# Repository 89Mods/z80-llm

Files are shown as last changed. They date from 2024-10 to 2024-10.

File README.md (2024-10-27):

# What?

Z80-LLM is a bunch of code meant to enable a Z80 CPU to run a GPT-2-Medium sized LLM, but larger should theoretically be possible. This will hopefully finally bring modern AI into the retro-computing era. The code is written in simple C and should be easily portable to platforms not just based on the Z80, but also other retro CPUs with a C compiler toolchain.

# Why?

# How?

## Hardware

The demo hardware consist only of a Z80, 32KiB of ROM and some SRAM. 32KiB is not enough, so the final 16KiB of the address range is paged 16-ways to get a bit more. Though technically less memory usage is possible at the cost of speed. Obviously, running a LLM requires still more memory, so two PIO chips drive a PATA interface to a disk drive, where data is paged in and out of raw disk blocks to get even more space for matrices and vectors. Part of the disk is formated, though, to hold the network parameters.

Two UARTs are provided: one for standard output and a second to print a verbose log.

The schematics and PCB layout files can be found in the folder `Hardware`.

## LLM

The code to pre-train the LLM was written using libtorch in C++, using custom code for implementation of the attention layers, to make translating it into standalone C easier. This code was then supplied with a dataset of book texts and trained on a cloud compute instance containing a RTX4090 that was fed a large budget of 27.16$. The resulting LLM is good enough at generating basic, coherent text for the purposes of demonstration.

This code can be found in the folder `libtorch_llm`.

## Standalone C program

I started out by writing a standalone, single file C program on my desktop PC that can run the LLM, to have a working reference point when writing the code for the Z80.
Still, this program already contains key aspects of what is required on the Z80, such as parsing parameters from files and emulating matrices being stored in a block device.
The resulting code only depends on the standard library and compiles into a tiny executable on Linux.

This code can be found in the folder `c_pgm`.

## Z80 Firmware

z88dk was used to create the program to run the LLM on a Z80. It works as described above by using space on a connected disk drive as memory for matrices and the paged SRAM as cache for that memory. To load the parameters, a filesystem partition is also present on the disk. My choice of filesystem is, of course, ext4, to further modernize the software design. Only basic filesystem read access is supported, but code to handle checksum checking and symlink parsing is present and can be enabled, if required. This allows easy copying and modification of the network parameters on the disk from any common Linux distro!

Standard IEEE 32-bit floats are used for computation. I did experiment with 16-bit floats and fixed-point numbers, but they produced completely broken results due to precission errors. So floats are used, for maximum compatibility! Though, one optimization I did make use of is LUTs. Notably, the GeLU nonlinearity is implemented through a LUT in a file, which I found to be faster.

A byte-pair-encoder almost identical to the one used in GPT-2 is used for tokenization. I will admit, the code I wrote for it is not the best, but it successfully runs on the Z80, so I am happy with it. It also uses data stored on the filesystem to do the encoding.

Note: the resulting code does not fit into the 32KiB ROM. To work around this, the CPU copies some blocks from the disk to SRAM at bootup, allowing code to overflow into RAM. Any code changes require not only re-programming of the ROM, but also an update of the disk image. I apologize for this inconvenience.

This code can be found in the folder `Z80`.

# Speed

At 8MHz and using a SSD as the disk drive for maximum throughput, I have approximated, using simulation, a time of 1,292,518 minutes per token, or roughly 2.4 years. Upgrading to a 20MHz Z80 should cut that down to 1 year, and I am investigating speeds using a AM9511 to accelerate the floating-point computations.

# Usage

The intended method for getting this beast running is to put together a disk image on your PC, and then dd-ing it to a real drive. Open a terminal at the root of this repository.

First, create a blank file that is less than or equal in capacity to your target physical drive. I am using a SSD with slightly less than 16GiB capacity, so I will use a 3G large image: `dd if=/dev/zero of=./disk.img bs=1M count=3072`

Next, it needs a filesystem partition. It can’t span the whole disk, as the program requires a bit of free space after the filesystem partition, which it will use as memory. Use fdisk for this: `fdisk ./disk.img`

Create a MBR partition table (`o`) and add a new partition (`n`), which is to be primary (`p`) and number 1 (`1`). First sector has to be 2048, as the first blocks of the disk past the MBR will store Z80 bytecode that is overflowing from ROM into RAM. For the size of the partition, I go with 2G (`+2G`) so mkfs doesn’t make a fuzz on the next step.

`w` will tell fdisk to write changes to the disk image and exit. To continue, the disk image needs to be set up as a loop device, so it can be worked on directly: `sudo losetup -fP disk.img`. For the next steps, make sure you are targeting the correct device, or you may corrupt a part of your OS! `lsblk` shows one new device, `loop0`, after the previous command, so that has to be it.

Simply doing `sudo mkfs.ext4 /dev/loop0p1` will create the ext4 file system on the partition that was just created. Note: it is possible your distro’s mkfs config enables filesystem features not supported by my code. If this happens, you can comment out the FS feature check in `Z80/ext4.c`. In most cases, it will still work.

At this point, you should be able to minimize the terminal window and continue in your DE’s file browser, as the freshly formatted partition should show up there, like a removable drive. Open it. You can change the permissions to make these next steps easier if you want, it won’t affect things on the Z80.

For now, I will only describe how to install the weights from my pre-trained model. Download the files [here](https://files.tholin.dev/Public/model.tar.gz) and extract into the root of the partition.

Next is the data files for the tokenizer. Navigate to `libtorch_llm/data/` directory and simply run the `prepare_vocab.sh` bash script. I decided to use GPT-2’s actual tokenizer configs, and this script will download them and apply any required modifications. You can then copy the entire `data` folder to the root of the ext4 partition.

Note: you will need nodejs installed to run one of the helper scripts. Yes, I am aware of how absolutely insane the language spread of this repository is.

Once done, the root of the partition should have three entries `LUTs`, `model` and `data`. You can now un-mount the partition. To remove the loop device, I like to use this handy command, which destroys all loop devices associated with a specific file: `losetup -j ./disk.img | grep -o "/dev/loop[0-9][0-9]*" | xargs -L1 sudo losetup -d`.

Now, finally, comes the step of building the Z80 code. Start by installing [z88dk](https://github.com/z88dk/z88dk/) in whichever way you prefer. Then, navigate a terminal to the `Z80` directory in this repo and simply do `make`. The makefile should do everything for you, including modifying the disk image with the overflowing binary (assuming you created it in the right place).

Lastly, get out whatever ROM programmer you use and burn `EPROM.bin` onto a memory chip of your choice. In parallel, start copying the disk image to a real drive, preferably through dd.

Congratulations! You are now ready to wait 2.5 years for your Z80 to say a single word to you!

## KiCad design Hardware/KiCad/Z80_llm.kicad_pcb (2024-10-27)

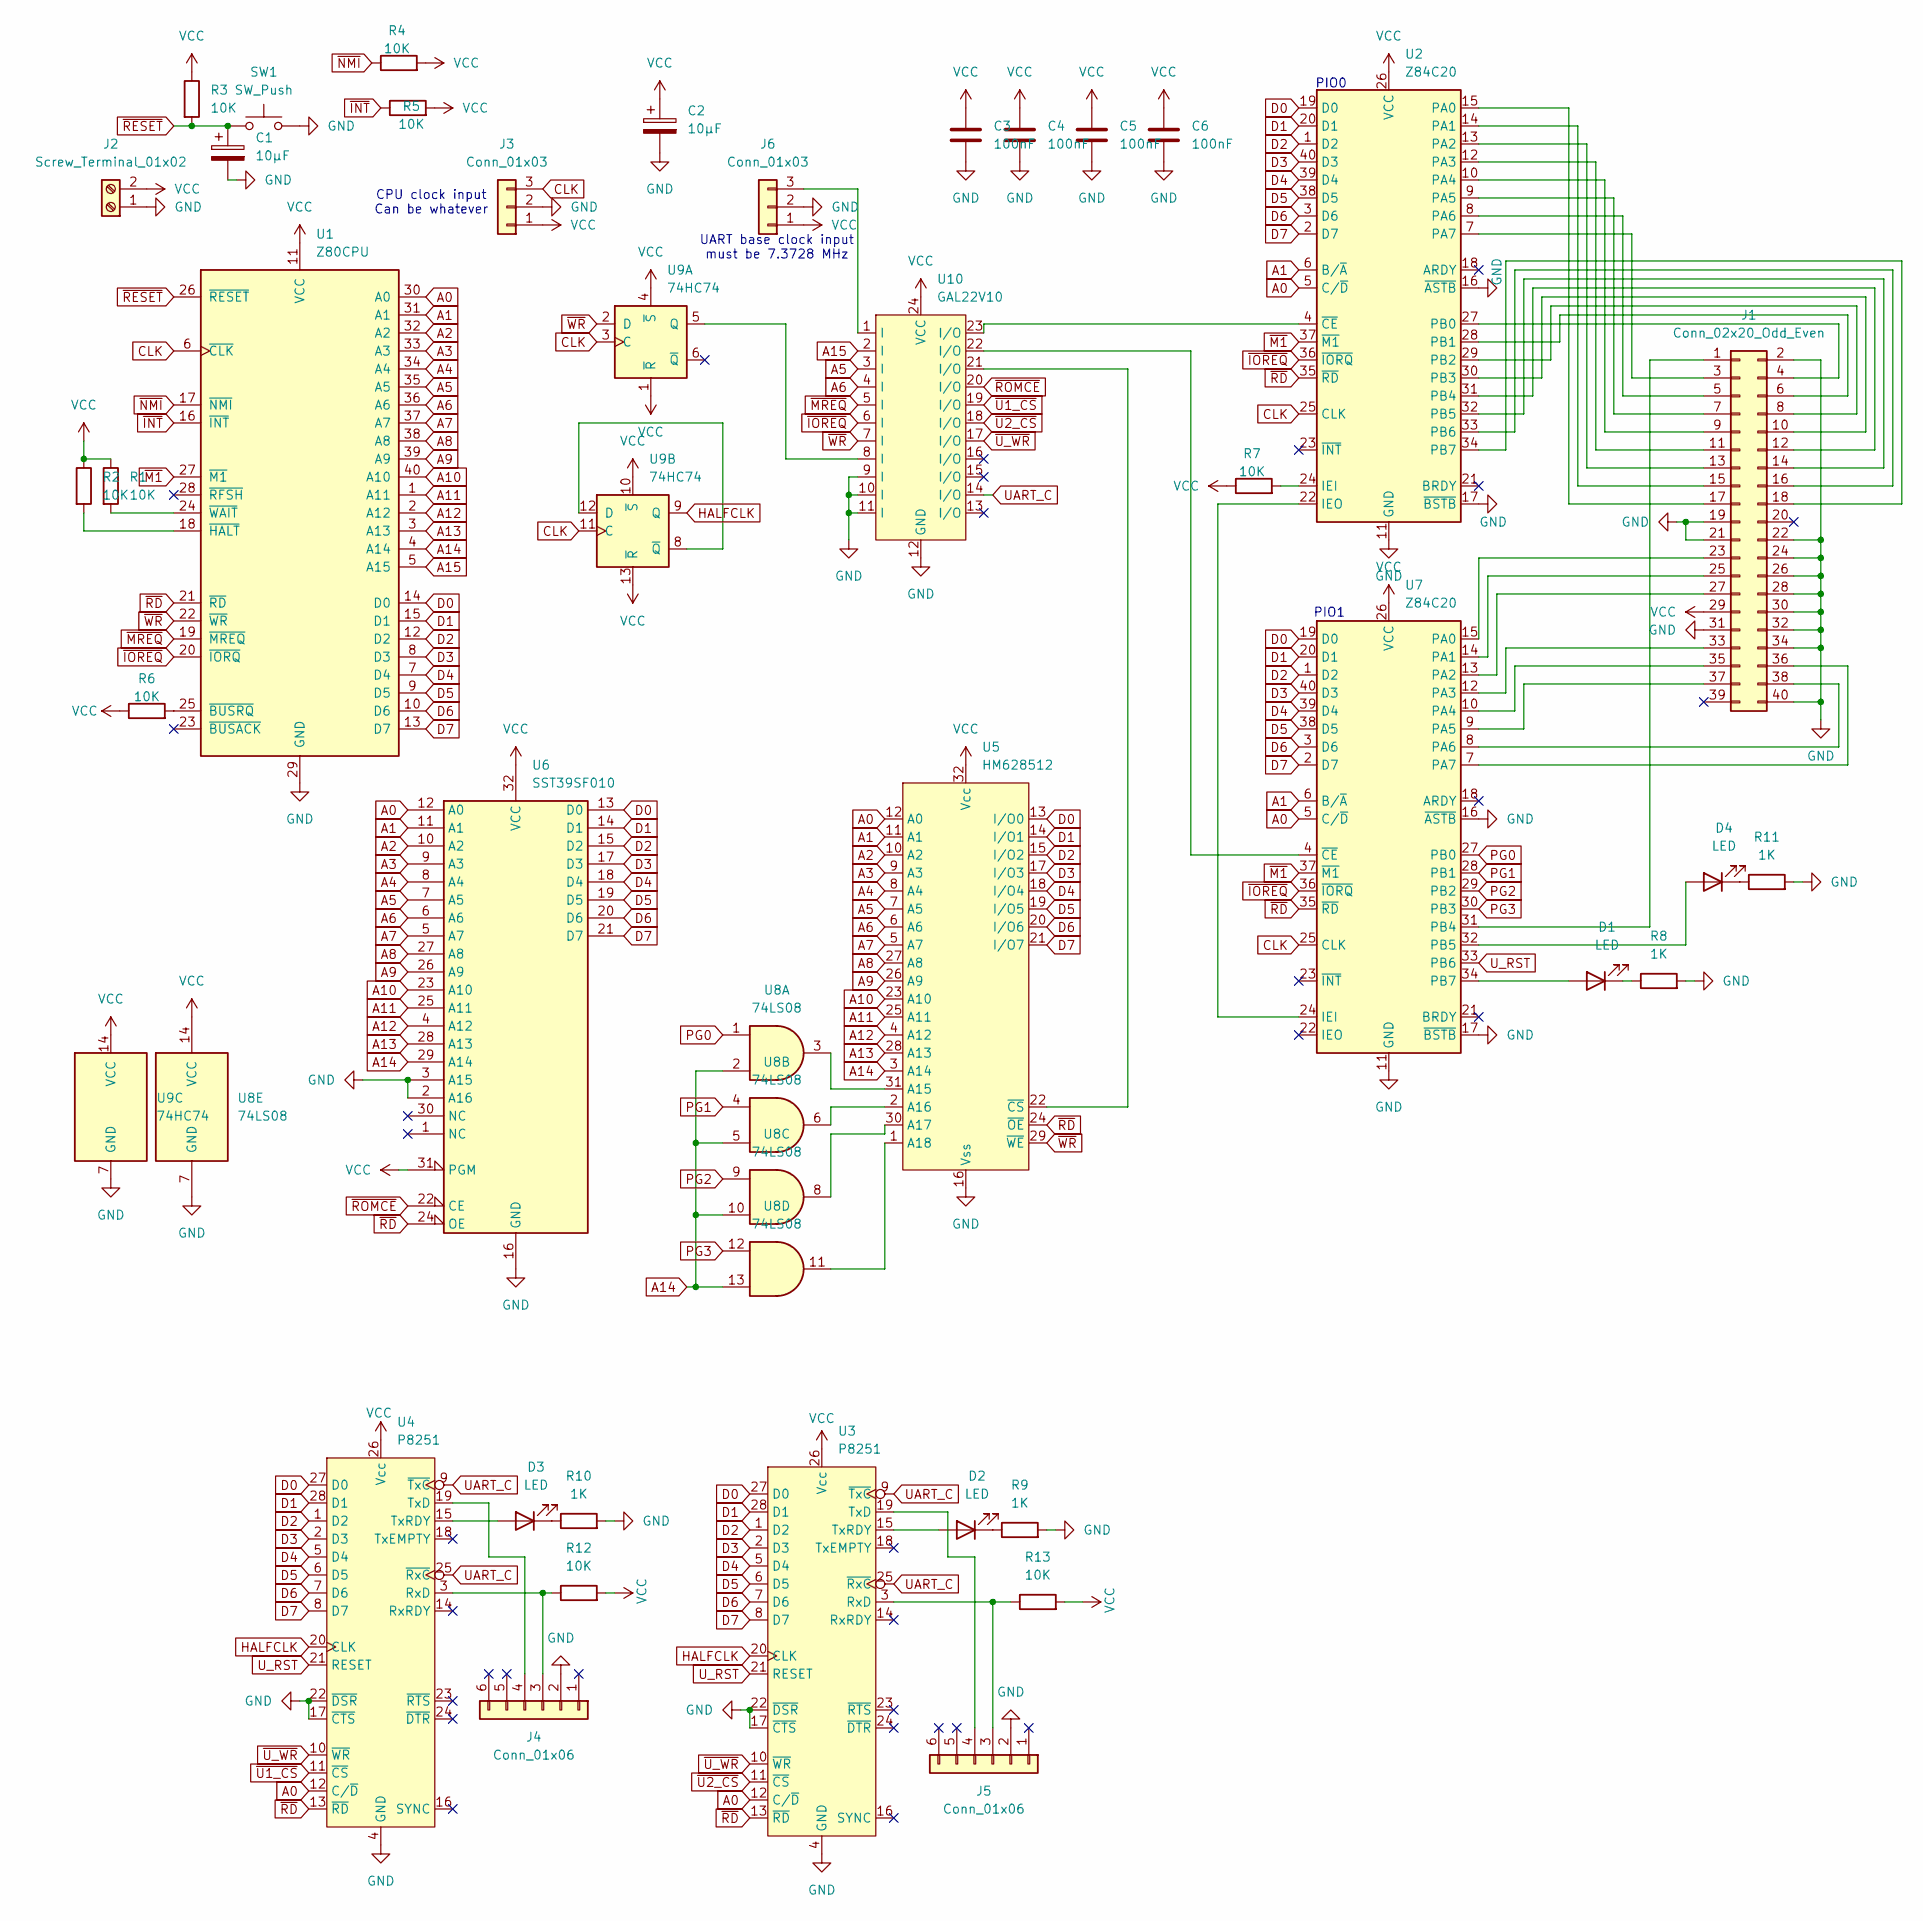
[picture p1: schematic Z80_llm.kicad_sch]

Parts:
C1, C2: 10µF; CP_Radial_D4.0mm_P2.00mm
C3, C4, C5, C6: 100nF; C_0805_2012Metric_Pad1.18x1.45mm_HandSolder
D1: LED; LED_D5.0mm
D2, D3, D4: LED; LED_D3.0mm
J1: Conn_02x20_Odd_Even; PinHeader_2x20_P2.54mm_Vertical
J2: Screw_Terminal_01x02; TerminalBlock_bornier-2_P5.08mm
J3, J6: Conn_01x03; PinHeader_1x03_P2.54mm_Vertical
J4, J5: Conn_01x06; PinHeader_1x06_P2.54mm_Vertical
R1, R2, R3, R4, R5, R6, R7, R12, R13: 10K; R_1206_3216Metric_Pad1.30x1.75mm_HandSolder
R8, R9, R10, R11: 1K; R_1206_3216Metric_Pad1.30x1.75mm_HandSolder
SW1: SW_Push; SW_PUSH_6mm
U1: Z80CPU; DIP-40_W15.24mm
U2, U7: Z84C20; DIP-40_W15.24mm
U3, U4: P8251; DIP-28_W15.24mm
U5: HM628512; DIP-32_W15.24mm
U6: SST39SF010; DIP-32_W15.24mm
U8: 74LS08; SO-14_3.9x8.65mm_P1.27mm
U9: 74HC74; DIP-14_W7.62mm
U10: GAL22V10; DIP-24_W7.62mm_Socket

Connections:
A0: U1.30 (A0), U2.5 (C/~D), U3.12 (C/~D), U4.12 (C/~D), U5.12 (A0), U6.12 (A0), U7.5 (C/~D)
A1: U1.31 (A1), U2.6 (B/~A), U5.11 (A1), U6.11 (A1), U7.6 (B/~A)
A2: U1.32 (A2), U5.10 (A2), U6.10 (A2)
A3: U1.33 (A3), U5.9 (A3), U6.9 (A3)
A4: U1.34 (A4), U5.8 (A4), U6.8 (A4)
A5: U1.35 (A5), U5.7 (A5), U6.7 (A5), U10.3 (I)
A6: U1.36 (A6), U5.6 (A6), U6.6 (A6), U10.4 (I)
A7: U1.37 (A7), U5.5 (A7), U6.5 (A7)
A8: U1.38 (A8), U5.27 (A8), U6.27 (A8)
A9: U1.39 (A9), U5.26 (A9), U6.26 (A9)
A10: U1.40 (A10), U5.23 (A10), U6.23 (A10)
A11: U1.1 (A11), U5.25 (A11), U6.25 (A11)
A12: U1.2 (A12), U5.4 (A12), U6.4 (A12)
A13: U1.3 (A13), U5.28 (A13), U6.28 (A13)
A14: U1.4 (A14), U5.3 (A14), U6.29 (A14), U8.2, U8.5, U8.10, U8.13
A15: U1.5 (A15), U10.2 (I)
CLK: J3.3, U1.6 (~CLK), U2.25 (CLK), U7.25 (CLK), U9.3 (C), U9.11 (C)
D0: U1.14 (D0), U2.19 (D0), U3.27 (D0), U4.27 (D0), U5.13 (I/O0), U6.13 (D0), U7.19 (D0)
D1: U1.15 (D1), U2.20 (D1), U3.28 (D1), U4.28 (D1), U5.14 (I/O1), U6.14 (D1), U7.20 (D1)
D2: U1.12 (D2), U2.1 (D2), U3.1 (D2), U4.1 (D2), U5.15 (I/O2), U6.15 (D2), U7.1 (D2)
D3: U1.8 (D3), U2.40 (D3), U3.2 (D3), U4.2 (D3), U5.17 (I/O3), U6.17 (D3), U7.40 (D3)
D4: U1.7 (D4), U2.39 (D4), U3.5 (D4), U4.5 (D4), U5.18 (I/O4), U6.18 (D4), U7.39 (D4)
D5: U1.9 (D5), U2.38 (D5), U3.6 (D5), U4.6 (D5), U5.19 (I/O5), U6.19 (D5), U7.38 (D5)
D6: U1.10 (D6), U2.3 (D6), U3.7 (D6), U4.7 (D6), U5.20 (I/O6), U6.20 (D6), U7.3 (D6)
D7: U1.13 (D7), U2.2 (D7), U3.8 (D7), U4.8 (D7), U5.21 (I/O7), U6.21 (D7), U7.2 (D7)
GND: C1.2, C2.2, C3.2, C4.2, C5.2, C6.2, J1.2, J1.19, J1.21, J1.22, J1.24, J1.26, J1.28, J1.30, J1.31, J1.32, J1.34, J1.40, J2.1, J3.2, J4.2, J5.2, J6.2, R8.2, R9.2, R10.2, R11.2, SW1.2, U1.29 (GND), U2.11 (GND), U2.16 (~ASTB), U2.17 (~BSTB), U3.4 (GND), U3.17 (~CTS), U3.22 (~DSR), U4.4 (GND), U4.17 (~CTS), U4.22 (~DSR), U5.16 (Vss), U6.2 (A16), U6.3 (A15), U6.16 (GND), U7.11 (GND), U7.16 (~ASTB), U7.17 (~BSTB), U8.7 (GND), U9.7 (GND), U10.9 (I), U10.10 (I), U10.11 (I), U10.12 (GND)
HALFCLK: U3.20 (CLK), U4.20 (CLK), U9.9 (Q)
unnamed: D1.2 (A), U7.34 (PB7)
unnamed: D1.1 (K), R8.1
unnamed: D2.2 (A), U3.15 (TxRDY)
unnamed: D2.1 (K), R9.1
unnamed: D3.2 (A), U4.15 (TxRDY)
unnamed: D3.1 (K), R10.1
unnamed: D4.2 (A), U7.32 (PB5)
unnamed: D4.1 (K), R11.1
unnamed: J1.1, U7.31 (PB4)
unnamed: J1.3, U2.7 (PA7)
unnamed: J1.4, U2.27 (PB0)
unnamed: J1.5, U2.8 (PA6)
unnamed: J1.6, U2.28 (PB1)
unnamed: J1.7, U2.9 (PA5)
unnamed: J1.8, U2.29 (PB2)
unnamed: J1.9, U2.10 (PA4)
unnamed: J1.10, U2.30 (PB3)
unnamed: J1.11, U2.12 (PA3)
unnamed: J1.12, U2.31 (PB4)
unnamed: J1.13, U2.13 (PA2)
unnamed: J1.14, U2.32 (PB5)
unnamed: J1.15, U2.14 (PA1)
unnamed: J1.16, U2.33 (PB6)
unnamed: J1.17, U2.15 (PA0)
unnamed: J1.18, U2.34 (PB7)
unnamed: J1.23, U7.15 (PA0)
unnamed: J1.25, U7.14 (PA1)
unnamed: J1.27, U7.13 (PA2)
unnamed: J1.33, U7.12 (PA3)
unnamed: J1.35, U7.10 (PA4)
unnamed: J1.36, U7.7 (PA7)
unnamed: J1.37, U7.9 (PA5)
unnamed: J1.38, U7.8 (PA6)
unnamed: J4.3, R12.1, U4.3 (RxD)
unnamed: J4.4, U4.19 (TxD)
unnamed: J5.3, R13.1, U3.3 (RxD)
unnamed: J5.4, U3.19 (TxD)
unnamed: J6.3, U10.1 (I)
unnamed: R6.2, U1.25 (~BUSRQ)
unnamed: R2.2, U1.18 (~HALT)
unnamed: R1.2, U1.24 (~WAIT)
unnamed: R7.2, U2.24 (IEI)
unnamed: U2.22 (IEO), U7.24 (IEI)
unnamed: U2.4 (~CE), U10.23 (I/O)
unnamed: U5.31 (A15), U8.3
unnamed: U5.2 (A16), U8.6
unnamed: U5.30 (A17), U8.8
unnamed: U5.1 (A18), U8.11
unnamed: U5.22 (~CS), U10.21 (I/O)
unnamed: U7.4 (~CE), U10.22 (I/O)
unnamed: U9.5 (Q), U10.8 (I)
unnamed: U9.8 (~Q), U9.12 (D)
PG0: U7.27 (PB0), U8.1
PG1: U7.28 (PB1), U8.4
PG2: U7.29 (PB2), U8.9
PG3: U7.30 (PB3), U8.12
UART_C: U3.9 (~TxC), U3.25 (~RxC), U4.9 (~TxC), U4.25 (~RxC), U10.14 (I/O)
U_RST: U3.21 (RESET), U4.21 (RESET), U7.33 (PB6)
VCC: C2.1, C3.1, C4.1, C5.1, C6.1, J1.29, J2.2, J3.1, J6.1, R1.1, R2.1, R3.1, R4.2, R5.2, R6.1, R7.1, R12.2, R13.2, U1.11 (VCC), U2.26 (VCC), U3.26 (Vcc), U4.26 (Vcc), U5.32 (Vcc), U6.31 (PGM), U6.32 (VCC), U7.26 (VCC), U8.14 (VCC), U9.1 (~R), U9.4 (~S), U9.10 (~S), U9.13 (~R), U9.14 (VCC), U10.24 (VCC)
~INT: R5.1, U1.16 (~INT)
~IOREQ: U1.20 (~IORQ), U2.36 (~IORQ), U7.36 (~IORQ), U10.6 (I)
~M1: U1.27 (~M1), U2.37 (~M1), U7.37 (~M1)
~MREQ: U1.19 (~MREQ), U10.5 (I)
~NMI: R4.1, U1.17 (~NMI)
~RD: U1.21 (~RD), U2.35 (~RD), U3.13 (~RD), U4.13 (~RD), U5.24 (~OE), U6.24 (OE), U7.35 (~RD)
~RESET: C1.1, R3.2, SW1.1, U1.26 (~RESET)
~ROMCE: U6.22 (CE), U10.20 (I/O)
~U1_CS: U4.11 (~CS), U10.19 (I/O)
~U2_CS: U3.11 (~CS), U10.18 (I/O)
~U_WR: U3.10 (~WR), U4.10 (~WR), U10.17 (I/O)
~WR: U1.22 (~WR), U5.29 (~WE), U9.2 (D), U10.7 (I)

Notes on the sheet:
UART base clock input must be 7.3728 MHz
CPU clock input Can be whatever
PIO0
PIO1

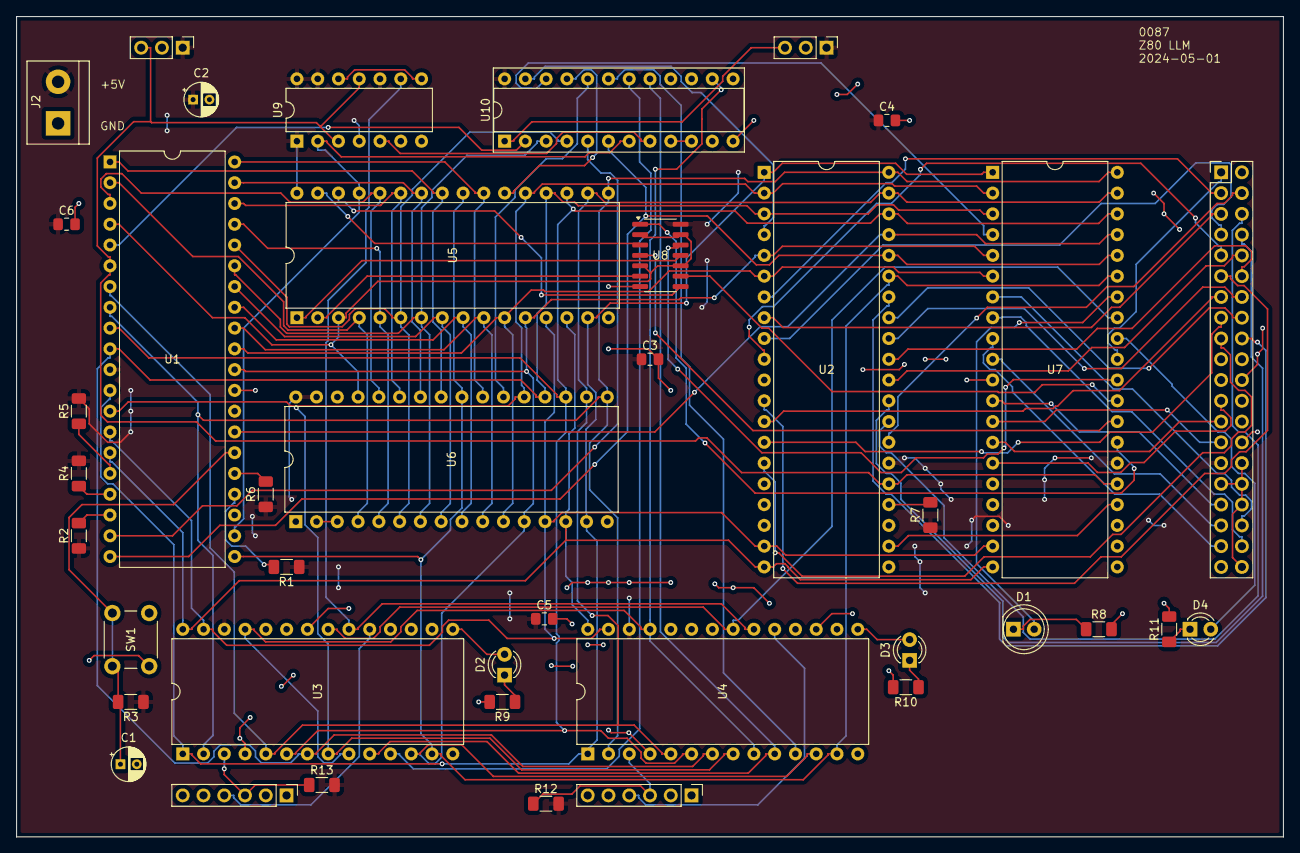
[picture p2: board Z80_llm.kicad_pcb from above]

Board: 2 copper layers, 154.9 x 100.3 mm, 40 parts (0 on the bottom side), 98 nets.

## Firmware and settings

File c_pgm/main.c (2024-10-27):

#include <stdio.h>
#include <stdint.h>
#include <stdlib.h>
#include <math.h>

#include "crc16.h"
#include "tokenizer.h"

#define EMULATED_BUFFERS

void print_cv_sample();

float f_inv_sqrt(float x) {
	if(x < 0) x = -x;
	float x2,y = 0;
	uint32_t i;

	if(x == 0.0f) return 0.0f;
	x2 = x * 0.5f;
	i = *(uint32_t *)&x;
	i = 0x5f3759df - (i >> 1);
	y = *(float *)&i;
	y *= 1.5f - (x2 * y * y);
	y *= 1.5f - (x2 * y * y);
	y *= 1.5f - (x2 * y * y);
	return y;
}

/*
 * Emulate Z80 disk buffers
 */
float context_vec[512][1024];
void cv_write_arr(uint16_t x, float* vals, uint16_t len) {
    for(uint16_t i = 0; i < len; i++) context_vec[x][i] = vals[i];
}

void cv_write_arr64(uint16_t x, uint16_t y, float* vals) {
	for(uint16_t i = 0; i < 64; i++) context_vec[x][i + y*64] = vals[i];
}

void cv_read_arr(uint16_t x, float* vals, uint16_t len) {
    for(uint16_t i = 0; i < len; i++) vals[i] = context_vec[x][i];
}

float context_shortcut[512][1024];
void cv_create_shortcut() {
	float raw[1024];
	for(uint16_t i = 0; i < 512; i++) {
		cv_read_arr(i, raw, 1024);
		for(uint16_t j = 0; j < 1024; j++) context_shortcut[i][j] = raw[j];
	}
}

void cv_add_shortcut() {
	float buff[1024];
	float buff2[1024];
	for(uint16_t i = 0; i < 512; i++) {
		cv_read_arr(i, buff, 1024);
		for(uint16_t j = 0; j < 1024; j++) buff2[j] = context_shortcut[i][j];
		for(uint16_t j = 0; j < 1024; j++) buff[j] += buff2[j];
		cv_write_arr(i, buff, 1024);
	}
}

float context_copy[512][1024]; //For when an operation needs to both update the context vector while needing its old values again
void cv_create_copy() {
	float raw[1024];
	for(uint16_t i = 0; i < 512; i++) {
		cv_read_arr(i, raw, 1024);
		for(uint16_t j = 0; j < 1024; j++) context_copy[i][j] = raw[j];
	}
}

void cv_read_copy_arr(uint16_t x, float* vals, uint16_t len) {
    for(uint16_t i = 0; i < len; i++) vals[i] = context_copy[x][i];
}

FILE* gelu_lut;

float f_gelu(float xf) {
	int32_t xi = (int32_t)(xf * 65536.0f);
	if(xi >= 0x00100000) return xf;
	if(xi <= -0x00100000) return 0.0f;
	uint32_t faddr = xi * 4;
	if(xi < 0) {
		xi = -xi;
		faddr = xi * 4 + 0x00100000*4;
	}
	fseek(gelu_lut, faddr, SEEK_SET);
	int32_t res;
	fread(&res, 1, 4, gelu_lut);
	return (float)res / 65536.0f;
}

typedef struct {
	uint16_t rows;
	uint16_t cols;
	uint32_t start_block;
#ifdef EMULATED_BUFFERS
	float* data;
#endif
} matrix_buff;

void mb_read_row(matrix_buff* bf, uint16_t row, float* vals) {
	for(uint16_t i = 0; i < bf->cols; i++) vals[i] = bf->data[(uint32_t)row * (uint32_t)bf->cols + i];
}

void mb_write_row(matrix_buff* bf, uint16_t row, float* vals) {
	for(uint16_t i = 0; i < bf->cols; i++) bf->data[(uint32_t)row * (uint32_t)bf->cols + i] = vals[i];
}

void mb_write_block(matrix_buff* bf, uint16_t row, uint16_t row_block, float* vals) {
	for(uint16_t i = 0; i < 512/4; i++) bf->data[(uint32_t)row * (uint32_t)bf->cols + i + row_block * (512/4)] = vals[i];
}

matrix_buff keys_matrix;
matrix_buff queries_matrix;
matrix_buff values_matrix;
matrix_buff values_transposed_matrix;
matrix_buff kq_matrix;
matrix_buff ff_matrix;

uint32_t cv_hash() {
    uint32_t hash = 0;
    float raw[1024];
    for(int i = 0; i < 512; i++) {
        cv_read_arr(i, raw, 1024);
        uint32_t crc = (uint32_t)gen_crc16((uint8_t*)raw, 1024*4);
        if(i % 2) {
            hash ^= crc << 16;
        }else {
            hash ^= crc;
        }
    }
    return hash;
}

void batch_norm(FILE* bparams) {
	float buff[1024];
	float buff2[1024];
	float* mean = buff2;
	float* var = buff2 + 512;
	for(uint16_t i = 0; i < 512; i++) {
		cv_read_arr(i, buff, 1024);
		mean[i] = 0;
		for(int j = 0; j < 1024; j++) mean[i] += buff[j];
		mean[i] = mean[i] / 1024.0f;
	}
	for(uint16_t i = 0; i < 512; i++) {
		cv_read_arr(i, buff, 1024);
		var[i] = 0;
		for(int j = 0; j < 1024; j++) {
			buff[j] -= mean[i];
			var[i] += buff[j] * buff[j];
		}
		var[i] = var[i] / 1023.0f;
		var[i] = f_inv_sqrt(var[i]);
		//if(i < 20) printf("%f %f\r\n", sqrt(f_tofloat(var[i])), f_tofloat(f_sqrt(var[i])));
	}
	
	for(uint16_t i = 0; i < 512; i++) {
		cv_read_arr(i, buff, 1024);
		for(int j = 0; j < 1024; j++) {
			buff[j] -= mean[i];
			buff[j] = buff[j] * var[i];
		}
		cv_write_arr(i, buff, 1024);
	}
	
	rewind(bparams);
	fread(buff2, 1024, 4, bparams);
	
	for(uint16_t i = 0; i < 512; i++) {
		cv_read_arr(i, buff, 1024);
		for(int j = 0; j < 1024; j++) buff[j] = buff[j] * buff2[j];
		cv_write_arr(i, buff, 1024);
	}
	
	fread(buff2, 1024, 4, bparams);
	for(uint16_t i = 0; i < 512; i++) {
		cv_read_arr(i, buff, 1024);
		for(int j = 0; j < 1024; j++) buff[j] += buff2[j];
		cv_write_arr(i, buff, 1024);
		//if(i == 0) for(int j = 0; j < 20; j++) printf("%f\r\n", f_tofloat(buff[j]));
	}
}

void matrix_multiply_with_embeddings(FILE* weights_file, matrix_buff* output) {
	float buffer[1024];
	float buffer2[1024];
	float buffer3[2048];
	for(uint16_t i = 0; i < output->rows; i++) {
		cv_read_copy_arr(i, buffer, 1024);
		rewind(weights_file);
		for(uint16_t j = 0; j < output->cols; j++) {
			fread(buffer2, 4, 1024, weights_file);
			float sum = 0;
			for(uint16_t k = 0; k < 1024; k++) sum += buffer[k] * buffer2[k];
			buffer3[j] = sum;
		}
		mb_write_row(output, i, buffer3);
	}
}

void feed_forward(FILE* in_params, FILE* out_params) {
	cv_create_copy();
	matrix_multiply_with_embeddings(in_params, &ff_matrix);
	float buffer[2048];
	float buffer2[2][2048];
	//Add bias
	fseek(in_params, 1024*2048*sizeof(float), SEEK_SET);
	fread(buffer2[0], 4, 2048, in_params);
	for(uint16_t i = 0; i < ff_matrix.rows; i++) {
		mb_read_row(&ff_matrix, i, buffer);
		for(uint16_t j = 0; j < ff_matrix.cols; j++) {
			buffer[j] += buffer2[0][j];
			buffer[j] = f_gelu(buffer[j]);
		}
		mb_write_row(&ff_matrix, i, buffer);
	}
	//Matmul
	for(uint16_t i = 0; i < 512; i++) {
		mb_read_row(&ff_matrix, i, buffer);
		rewind(out_params);
		for(uint16_t j = 0; j < 1024; j++) {
			fread(buffer2[0], 4, ff_matrix.cols, out_params);
			float sum = 0;
			for(uint16_t k = 0; k < ff_matrix.cols; k++) sum += buffer[k] * buffer2[0][k];
			buffer2[1][j] = sum;
		}
		cv_write_arr(i, buffer2[1], 1024);
	}
	//Add bias
	fseek(out_params, 2048*1024*sizeof(float), SEEK_SET);
	fread(buffer2[0], 4, 1024, out_params);
	for(uint16_t i = 0; i < 512; i++) {
		cv_read_arr(i, buffer, 1024);
		for(uint16_t j = 0; j < 1024; j++) buffer[j] += buffer2[0][j];
		cv_write_arr(i, buffer, 1024);
		//if(i == 508) for(uint16_t j = 0; j < 1024; j++) printf("%f\r\n", f_tofloat(buffer[j]));
	}
}

//sqrt(context_size) = sqrt(512)
#define SDK 22.627416998f

void self_attention(uint8_t which) {
	char fn_buffer[42];
	cv_create_copy();
	float buffer[64];
	float buffer2[64];
	float buffer3[512];
	float buffer4[512];
	for(uint8_t i = 0; i < 16; i++) {
		printf("\r%02X", i+1);
		fflush(stdout);
		sprintf(fn_buffer, "model/block%u/attention/%u/keys.bin", which, i);
		FILE* weights_file;
		weights_file = fopen(fn_buffer, "rb");
		matrix_multiply_with_embeddings(weights_file, &keys_matrix);
		fclose(weights_file);
		
		sprintf(fn_buffer, "model/block%u/attention/%u/queries.bin", which, i);
		weights_file = fopen(fn_buffer, "rb");
		matrix_multiply_with_embeddings(weights_file, &queries_matrix);
		fclose(weights_file);
		
		sprintf(fn_buffer, "model/block%u/attention/%u/values.bin", which, i);
		weights_file = fopen(fn_buffer, "rb");
		matrix_multiply_with_embeddings(weights_file, &values_matrix);
		fclose(weights_file);
		
		//Keys x queries
		const float div_by = SDK;
		for(uint16_t j = 0; j < 512; j++) {
			mb_read_row(&queries_matrix, j, buffer);
			for(uint16_t k = 0; k < j+1; k++) {
				mb_read_row(&keys_matrix, k, buffer2); //TODO: cache this
				float sum = 0;
				for(uint16_t l = 0; l < 64; l++) sum += buffer[l] * buffer2[l];
				buffer3[k] = sum / div_by;
			}
			for(uint16_t k = j+1; k < 512; k++) {
				buffer3[k] = 0;
			}
			//if(j == 511) for(uint16_t k = 0; k < 512; k++) printf("%f\r\n", f_tofloat(buffer3[k]));
			mb_write_row(&kq_matrix, j, buffer3);
		}
		
		//Softmax
		for(uint16_t j = 0; j < 512; j++) {
			mb_read_row(&kq_matrix, j, buffer3);
			if(j == 0) buffer3[0] = 1;
			else {
				float sum = 0;
				for(int k = 0; k < j+1; k++) {
					buffer3[k] = exp(buffer3[k]);
				}
				for(int k = 0; k < j+1; k++) sum += buffer3[k];
				if(sum == 0) printf("\r\n%d %d\r\n", which, j);
				for(int k = 0; k < j+1; k++) {
					buffer3[k] = buffer3[k] / sum;
					//if(which == 9 && j == 47) printf("%f\r\n", f_tofloat(buffer3[k]));
				}
			}
			
			//if(j == 32) for(int k = 0; k < 512; k++) printf("%f\r\n", f_tofloat(buffer3[k]));
			
			mb_write_row(&kq_matrix, j, buffer3);
		}
		
		//The values matrix needs to be transposed
		float paged_buffer[4][4096];
		float block_buffer[128];
		for(uint16_t j = 0; j < 512/128; j++) {
			uint16_t buffer_pos = 0;
			for(uint16_t k = 0; k < 128; k++) {
				mb_read_row(&values_matrix, j*128+k, paged_buffer[buffer_pos>>12]+(buffer_pos&0xFFF));
				buffer_pos += 64;
			}
			for(uint16_t k = 0; k < 64; k++) {
				for(uint16_t l = 0; l < 128; l++) {
					uint32_t val_addr = l * 64 + k;
					block_buffer[l] = paged_buffer[val_addr>>12][val_addr&0xFFF];
				}
				mb_write_block(&values_transposed_matrix, k, j, block_buffer);
			}
		}
		
		//mb_read_row(&values_transposed_matrix, 63, buffer3);
		//for(uint16_t k = 0; k < 512; k++) printf("%f\r\n", f_tofloat(buffer3[k]));
		
		//Final matrix multiply of kq_matrix times transposed values
		for(uint16_t j = 0; j < 512; j++) {
			mb_read_row(&kq_matrix, j, buffer4);
			for(uint16_t k = 0; k < 64; k++) {
				mb_read_row(&values_transposed_matrix, k, buffer3);
				float sum = 0;
				for(uint16_t l = 0; l < 512; l++) sum += buffer4[l] * buffer3[l];
				buffer2[k] = sum;
				//if(i == 10 && j == 200) printf("%f\r\n", f_tofloat(sum));
			}
			cv_write_arr64(j, i, buffer2);
		}
	}
	printf("\r\n");
}

void print_cv_sample() {
	float debug_buff[1024];
	printf("Context vec sample:\n\t");
	for(uint8_t i = 0; i < 2; i++) {
		cv_read_arr(i == 0 ? 0 : 511, debug_buff, 1024);
		for(int k2 = 0; k2 < 10; k2++) printf("%f ", debug_buff[k2]);
		printf("[...] ");
		for(int k2 = 0; k2 < 10; k2++) printf("%f ", debug_buff[1023-9+k2]);
		printf("\n");
		if(i == 0) printf("\t");
	}
}

void main(void) {
    bpe_init();
    uint16_t tbuff[512];
    uint16_t np = tokenize("Anna stared out the window and watched the monotonous structures of the city quickly being replaced by an expanse of green fields. Underneath her, the old wheels of the train screeched and shuddered, vibrating her in her seat, the only one that was perfectly aligned with a window, as most of the others had been removed long ago, leaving the carriage mostly empty and its plain metal walls and floor entirely exposed. She was probably", tbuff);
    for(int i = 0; i < np; i++) {
        tbuff[511-i] = tbuff[np-1-i];
    }
    for(int i = 0; i < 512-np; i++) tbuff[i] = 0;
    //for(int i = 0; i < 512; i++) printf("%u ", tbuff[i]);
    //printf("\r\n");
    //char obuff[512];
    //untokenize(tbuff+512-np, np, obuff);
    //puts(obuff);
    
    keys_matrix.rows = 512;
	keys_matrix.cols = 64;
	keys_matrix.start_block = 0;
	keys_matrix.data = (float*)malloc(64*512*sizeof(float));
	
	queries_matrix.rows = 512;
	queries_matrix.cols = 64;
	queries_matrix.start_block = 0;
	queries_matrix.data = (float*)malloc(64*512*sizeof(float));;
	
	values_matrix.rows = 512;
	values_matrix.cols = 64;
	values_matrix.start_block = 0;
	values_matrix.data = (float*)malloc(64*512*sizeof(float));
	
	values_transposed_matrix.rows = 64;
	values_transposed_matrix.cols = 512;
	values_transposed_matrix.start_block = 0;
	values_transposed_matrix.data = (float*)malloc(512*64*sizeof(float));
	
	kq_matrix.rows = 512;
	kq_matrix.cols = 512;
	kq_matrix.start_block = 0;
	kq_matrix.data = (float*)malloc(512*512*sizeof(float));
    
	ff_matrix.rows = 512;
	ff_matrix.cols = 2048;
	ff_matrix.start_block = 0;
	ff_matrix.data = (float*)malloc(512*2048*sizeof(float));
	
	if(!keys_matrix.data || !queries_matrix.data || !values_matrix.data || !kq_matrix.data || !values_transposed_matrix.data) {
		printf("Memory allocation fail\r\n");
		exit(1);
	}
	
	gelu_lut = fopen("gelu.bin", "rb");
	
    //Layers
	const uint8_t num_iterations = 1;
    for(uint8_t iteration = 0; iteration < num_iterations; iteration++) {
		printf("Iteration %d\r\n", iteration+1);
		//Embedding
		{
			FILE *emb_fil;
			emb_fil = fopen("model/token_embeddings.bin", "rb");
			float raw[1024];
			float raw2[1024];
			for(int i = 0; i < 512; i++) {
				fseek(emb_fil, tbuff[i]*1024*sizeof(float), SEEK_SET);
				fread(raw, 1024, 4, emb_fil);
				cv_write_arr(i, raw, 1024);
			}
			fclose(emb_fil);
			emb_fil = fopen("model/positional_embeddings.bin", "rb");
			for(int i = 0; i < 512; i++) {
				fread(raw, 1024, 4, emb_fil);
				cv_read_arr(i, raw2, 1024);
				for(int j = 0; j < 1024; j++) raw[j] = raw[j] + raw2[j];
				cv_write_arr(i, raw, 1024);
			}
			fclose(emb_fil);
		}
		print_cv_sample();
		printf("%u\r\n", cv_hash());
		
		const uint8_t dump_layer = 9;
		char fname_buff[42];
		FILE *bparams;
		for(uint8_t i = 0; i < 24; i++) {
			printf("%u/%u\r\n", i+1, 24);
			if(i == dump_layer) {
				FILE *outfile = fopen("layerdump.bin", "wb");
				float wbuff[1024];
				for(int j = 0; j < 512; j++) {
					cv_read_arr(j, wbuff, 1024);
					fwrite(wbuff, 4, 1024, outfile);
				}
				fclose(outfile);
				printf("CV dumped at layer %u\r\n", dump_layer);
			}
			sprintf(fname_buff, "model/block%u/norm1.bin", i);
			bparams = fopen(fname_buff, "rb");
			cv_create_shortcut();
			batch_norm(bparams);
			fclose(bparams);
			print_cv_sample();
			self_attention(i);
			print_cv_sample();
			cv_add_shortcut();
			cv_create_shortcut();
			sprintf(fname_buff, "model/block%u/norm2.bin", i);
			bparams = fopen(fname_buff, "rb");
			batch_norm(bparams);
			fclose(bparams);
			sprintf(fname_buff, "model/block%u/dense/ff0.bin", i);
			bparams = fopen(fname_buff, "rb");
			FILE* out_params;
			sprintf(fname_buff, "model/block%u/dense/ff1.bin", i);
			out_params = fopen(fname_buff, "rb");
			feed_forward(bparams, out_params);
			fclose(bparams);
			fclose(out_params);
			cv_add_shortcut();
			print_cv_sample();
		}
		bparams = fopen("model/norm.bin", "rb");
		batch_norm(bparams);
		fclose(bparams);
		print_cv_sample();
		printf("%u\r\n", cv_hash());
		
		bparams = fopen("model/unembedding.bin", "rb");
		float buff[1024];
		float buff2[1024];
		float buff3[50257]; //temp
		const float temperature = 0.621f;
		cv_read_arr(511, buff, 1024); //Only interested in the latest prediction
		for(uint16_t i = 0; i < 50257; i++) {
			fread(buff2, 4, 1024, bparams);
			float sum = 0;
			for(uint16_t j = 0; j < 1024; j++) sum += buff[j] * buff2[j];
			sum = sum / temperature;
			buff3[i] = sum;
		}
		fclose(bparams);
		//Needs topk first
		uint16_t topk_idx[10];
		float topk_vals[10];
		for(uint8_t i = 0; i < 10; i++) topk_vals[i] = -10000;
		for(uint16_t i = 0; i < 50257; i++) {
			float val = buff3[i];
			if(topk_vals[0] >= val) continue;
			for(uint8_t j = 9; j != 255; j--) {
				if(val > topk_vals[j]) {
					if(j == 0) {
						topk_vals[j] = val;
						topk_idx[j] = i;
					}else {
						for(uint8_t k = 0; k < j; k++) {
							topk_vals[k] = topk_vals[k + 1];
							topk_idx[k] = topk_idx[k + 1];
						}
						topk_vals[j] = val;
						topk_idx[j] = i;
					}
					break;
				}
			}
		}
		
		printf("\r\ntopk:\r\n");
		for(uint8_t i = 0; i < 10; i++) {
			printf("%d - %f\r\n", topk_idx[i], topk_vals[i]);
		}
		printf("\r\n");
		
		float sum = 0;
		for(uint16_t i = 0; i < 10; i++) {
			topk_vals[i] = exp(topk_vals[i]);
			sum += topk_vals[i];
		}
		for(uint16_t i = 0; i < 10; i++) {
			topk_vals[i] = topk_vals[i] / sum;
			printf("%f\r\n", topk_vals[i]);
		}
		float random = (float)(rand() & 0xFFFF) / 65536.0f;
		uint16_t token;
		sum = 0;
		for(token = 0; token < 10; token++) {
			sum += topk_vals[token];
			if(sum >= random) break;
		}
		for(int i = 0; i < 511; i++) tbuff[i] = tbuff[i + 1];
		tbuff[511] = token == 10 ? 0 : topk_idx[token];
	}
    char obuff[512];
    untokenize(tbuff+512-np-num_iterations, np+num_iterations, obuff);
    puts(obuff);
	
	free(keys_matrix.data);
	free(queries_matrix.data);
	free(values_matrix.data);
	free(kq_matrix.data);
	free(values_transposed_matrix.data);
	free(ff_matrix.data);
	
	fclose(gelu_lut);
}

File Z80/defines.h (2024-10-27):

#ifndef DEFINES_H_
#define DEFINES_H_
#define ADDR_PIO0 0
#define ADDR_PIO1 32
#define ADDR_UART0 64
#define ADDR_UART1 96

#define UART_DATA 0
#define UART_COMMAND 1

#define PIO_DAT 0
#define PIO_CMD 1
#define PIO_A 0
#define PIO_B 2

#define LED_ERR 128
#define UART_RESET 64
#define LED_WHITE 32
#define PATA_RESET 16

#define PATA_DIOW 1
#define PATA_DIOR 2
#define PATA_IORDY 4
#define PATA_DA1 8
#define PATA_DA0 16
#define PATA_CS0 32
#define PATA_CS1 64
#define PATA_DA2 128

#define ATA_NOP (PATA_CS0|PATA_CS1)
#define ATA_DATA PATA_CS1
#define ATA_REG_STAT_CMD (PATA_CS1|PATA_DA0|PATA_DA1|PATA_DA2)
#define ATA_REG_ASTA_CTRL (PATA_CS0|PATA_DA2|PATA_DA1)
#define ATA_REG_ERR_FEAT (PATA_CS1|PATA_DA0)
#define ATA_REG_SECTOR_COUNT (PATA_CS1|PATA_DA1)
#define ATA_REG_ADDR (PATA_CS0|PATA_DA0|PATA_DA1|PATA_DA2)
#define ATA_REG_SECTOR_NUM (PATA_CS1|PATA_DA1|PATA_DA0)
#define ATA_REG_CYLINDER_LOW (PATA_CS1|PATA_DA2)
#define ATA_REG_CYLINDER_HIGH (PATA_CS1|PATA_DA2|PATA_DA0)
#define ATA_REG_DRIVE_HEAD (PATA_CS1|PATA_DA1|PATA_DA2)

#define ATA_CMD_DIAG 0x90
#define ATA_CMD_IDENT 0xEC
#define ATA_CMD_READ_SEC 0x21
#define ATA_CMD_WRITE_SEC 0x31

#define ATA_DRV_HEAD_BASE 0b11100000

void io_outp(uint16_t addr, uint8_t val);
unsigned char io_inp(uint16_t addr);
void puthex(uint8_t c);
void fatal();
void set_page(uint8_t page);
uint8_t get_page();
char getchar();
void check_uart_in();
void decr64(uint64_t* p);
void disable_text_buffer();
void enable_text_buffer();

#define HIGHMEM_START 0xC000

#endif

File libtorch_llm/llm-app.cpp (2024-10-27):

#include <torch/torch.h>
#include <iostream>
#include <fstream>
#include <string>
#include <vector>
#include <signal.h>
#include <dirent.h>
#include <sys/stat.h>
#include <random>
#include <filesystem>

#include "tokenizer.cpp"

uint32_t b_fromfloat(float x, bool* trunc);
int write_param(torch::Tensor& t, bool flip, std::ofstream& output);

struct SelfAttentionImpl : torch::nn::Module {
public:
	SelfAttentionImpl(int d_in, int d_out, int context_length, float dropout_rate) : dropout(dropout_rate) {
		assert(d_out > 0 && d_in > 0 && context_length > 0);
		float k = sqrt(1.0f / (float)d_in);
		W_query = register_parameter("Wq", torch::rand({d_in, d_out}) * (2*k) - k);
		W_key = register_parameter("Wk", torch::rand({d_in, d_out}) * (2*k) - k);
		W_value = register_parameter("Wv", torch::rand({d_in, d_out}) * (2*k) - k);
		mask = register_buffer("mask", torch::triu(torch::ones({context_length, context_length}), 1));
		register_module("drop", dropout);
		sdk = sqrt((double)context_length);
	}
	
	void save(std::string dir_base) {
		std::filesystem::create_directory(dir_base);
		{
			std::stringstream output_fn;
			output_fn << dir_base << "/keys.bin";
			std::ofstream output(output_fn.str(), std::ios::binary | std::ios::out);
			write_param(W_key, false, output);
			output.close();
		}
		{
			std::stringstream output_fn;
			output_fn << dir_base << "/queries.bin";
			std::ofstream output(output_fn.str(), std::ios::binary | std::ios::out);
			write_param(W_query, false, output);
			output.close();
		}
		{
			std::stringstream output_fn;
			output_fn << dir_base << "/values.bin";
			std::ofstream output(output_fn.str(), std::ios::binary | std::ios::out);
			write_param(W_value, false, output);
			output.close();
		}
	}
	
	torch::Tensor forward(torch::Tensor input) {
		torch::Tensor keys = torch::matmul(input, W_key);
		torch::Tensor queries = torch::matmul(input, W_query);
		torch::Tensor values = torch::matmul(input, W_value);
		
		auto transposed = torch::transpose(keys, 1, 2);
		torch::Tensor attn_scores = torch::matmul(queries, transposed);
		torch::Tensor masked = torch::masked_fill(attn_scores, mask.to(torch::ScalarType::Bool), -std::numeric_limits<float>::infinity());
		
		torch::Tensor smax = masked / sdk;
		smax = torch::softmax(smax, -1);
		torch::Tensor attn_weights = dropout->forward(smax);
		
		torch::Tensor context_vec = torch::matmul(attn_weights, values);
		
		return context_vec;
	}
private:
	torch::Tensor W_key, W_query, W_value, mask;
	torch::nn::Dropout dropout;
	float sdk;
};
TORCH_MODULE(SelfAttention);

/*class MultiHeadAttentionImpl : torch::nn::Module {
public:
	MultiHeadAttentionImpl(int d_in, int d_out, int context_length, float dropout_rate, int num_heads) {
		assert(num_heads > 0);
		for(int i = 0; i < num_heads; i++) {
			SelfAttention head(d_in, d_out, context_length, dropout_rate);
			heads.push_back(head);
			std::stringstream ss;
			ss << "h" << i;
			register_module(ss.str(), head);
		}
		out_dim = d_out;
	}
	
	void save(std::string dir_base) {
		std::filesystem::create_directory(dir_base);
		for(int i = 0; i < heads.size(); i++) {
			std::stringstream dir_name;
			dir_name << dir_base << "/" << i;
			heads[i]->save(dir_name.str());
		}
	}
	
	torch::Tensor forward(torch::Tensor input) {
		torch::Tensor result = torch::zeros({input.size(0), input.size(1), out_dim});
		for(int i = 0; i < heads.size(); i++) {
			result += heads[i]->forward(input);
		}
		return result;
	}
private:
	std::vector<SelfAttention> heads;
	int out_dim;
};
TORCH_MODULE(MultiHeadAttention);*/

struct MultiHeadAttentionAltImpl : torch::nn::Module {
public:
	MultiHeadAttentionAltImpl(int d_in, int d_out, int context_length, float dropout_rate, int num_heads) {
		assert(d_out % num_heads == 0);
		head_dim = d_out / num_heads;
		for(int i = 0; i < num_heads; i++) {
			SelfAttention head(d_in, head_dim, context_length, dropout_rate);
			heads.push_back(head);
			std::stringstream ss;
			ss << "h" << i;
			register_module(ss.str(), head);
		}
	}
	
	void save(std::string dir_base) {
		std::filesystem::create_directory(dir_base);
		for(int i = 0; i < heads.size(); i++) {
			std::stringstream dir_name;
			dir_name << dir_base << "/" << i;
			heads[i]->save(dir_name.str());
		}
	}
	
	torch::Tensor forward(torch::Tensor input) {
		torch::Tensor results[heads.size()];
		for(int i = 0; i < heads.size(); i++) {
			results[i] = heads[i]->forward(input);
		}
		torch::Tensor res = torch::cat(torch::ArrayRef<torch::Tensor>(results, heads.size()), -1);
		return res;
	}
private:
	std::vector<SelfAttention> heads;
	int head_dim;
};
TORCH_MODULE(MultiHeadAttentionAlt);

struct LayerNormImpl : torch::nn::Module {
public:
	LayerNormImpl(int emb_dim) {
		assert(emb_dim > 0);
		e = emb_dim;
		scale = register_parameter("sc", torch::ones({emb_dim}));
		shift = register_parameter("sh", torch::zeros({emb_dim}));
	}
	
	void save(std::string fn) {
		std::ofstream output(fn, std::ios::binary | std::ios::out);
		write_param(scale, false, output);
		write_param(shift, false, output);
		output.close();
	}
	
	torch::Tensor forward(torch::Tensor input) {
		torch::Tensor mean = input.mean(-1, true);
		torch::Tensor var = input.var(-1, false, true);
		torch::Tensor x = (input - mean) / torch::sqrt(var + eps);
		x = scale * x + shift;
		return x;
	}
private:
	float eps = 1e-5f;
	int e;
	torch::Tensor scale, shift;
};
TORCH_MODULE(LayerNorm);

struct FeedForwardImpl : torch::nn::Module {
public:
	FeedForwardImpl(int d_size) {
		float k = sqrt(1.0f / (float)d_size);
		W_in = register_parameter("Wi", torch::rand({d_size, 2*d_size}) * (2*k) - k);
		B_in = register_parameter("Bi", torch::zeros({2*d_size}));
		k = sqrt(1.0f / (float)(d_size*2));
		W_out = register_parameter("Wo", torch::rand({2*d_size, d_size}) * (2*k) - k);
		B_out = register_parameter("Bo", torch::zeros({d_size}));
	}
	
	void save(std::string dir_base) {
		std::filesystem::create_directory(dir_base);
		{
			std::stringstream output_fn;
			output_fn << dir_base << "/ff0.bin";
			std::ofstream output(output_fn.str(), std::ios::binary | std::ios::out);
			write_param(W_in, false, output);
			write_param(B_in, false, output);
			output.close();
		}
		{
			std::stringstream output_fn;
			output_fn << dir_base << "/ff1.bin";
			std::ofstream output(output_fn.str(), std::ios::binary | std::ios::out);
			write_param(W_out, false, output);
			write_param(B_out, false, output);
			output.close();
		}
	}
	
	torch::Tensor forward(torch::Tensor input) {
		torch::Tensor x = torch::matmul(input, W_in);
		x += B_in;
		x = torch::gelu(x);
		x = torch::matmul(x, W_out);
		return x + B_out;
	}
private:
	torch::Tensor W_in,B_in,W_out,B_out;
};
TORCH_MODULE(FeedForward);
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
